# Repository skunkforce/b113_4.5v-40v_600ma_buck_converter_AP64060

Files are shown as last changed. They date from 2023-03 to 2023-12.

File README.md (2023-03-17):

# edgy_board number b113
This design is part of the [edgy board project](https://github.com/skunkforce/edgy_boards).  

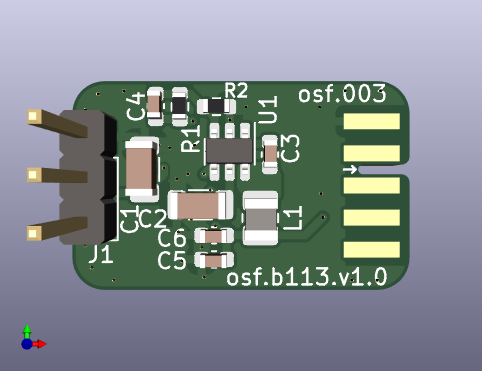
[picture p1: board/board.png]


# getting started
This repository uses submodules. After cloning use the command 

```$ git submodule update --init --recursive```

to pull the submodules before opening the project with kicad. 

# Tests
Tests can be found in [TESTS.md](TESTS.md)

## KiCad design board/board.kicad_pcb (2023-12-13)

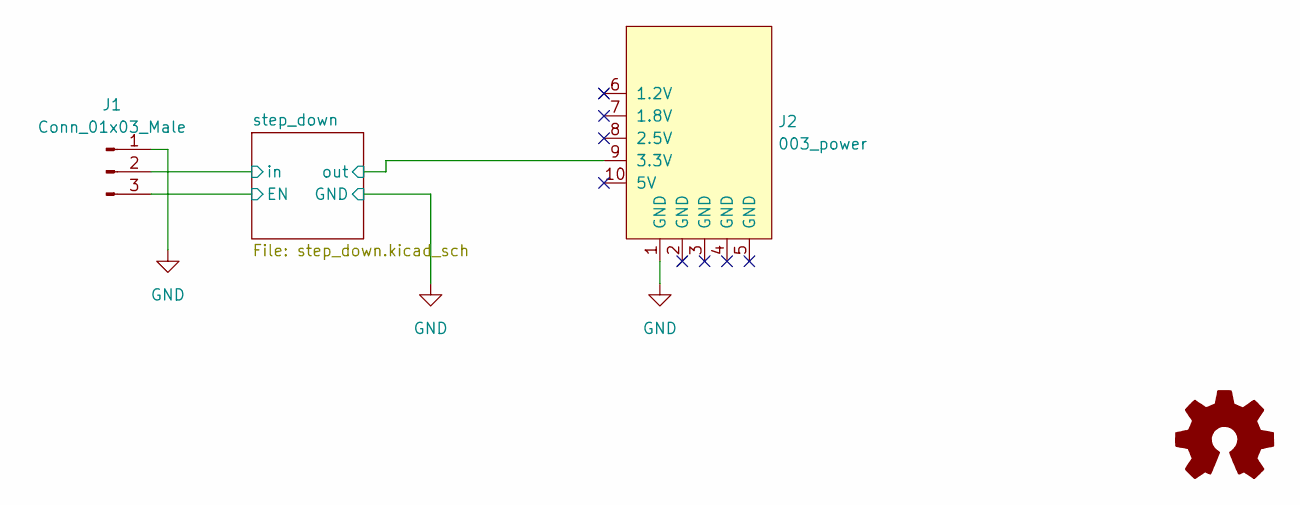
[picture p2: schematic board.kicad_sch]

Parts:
J1: Conn_01x03_Male; PinHeader_1x03_P2.54mm_Vertical
J2: 003_power; on_edge_2x05_host
LOGO1: Logo_Open_Hardware_Small; OSHW-Symbol_6.7x6mm_SilkScreen

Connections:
/step_down/EN: J1.3; also elsewhere on the board
/step_down/in: J1.2; also elsewhere on the board
/step_down/out: J2.9 (3.3V); also elsewhere on the board
GND: J1.1, J2.1 (GND); also elsewhere on the board

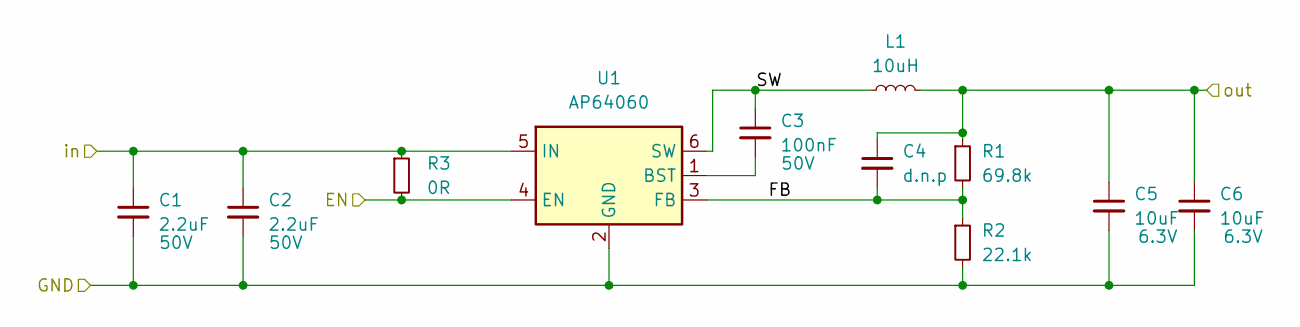
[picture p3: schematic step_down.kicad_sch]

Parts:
C1, C2: 2.2uF; C_1206_3216Metric; Voltage 50V
C3: 100nF; C_0603_1608Metric; Voltage 50V
C4: d.n.p; C_0603_1608Metric
C5, C6: 10uF; C_0603_1608Metric; Voltage 6.3V
L1: 10uH; L_1210_3225Metric; MPN CBC3225T100KR
R1: 69.8k; R_0603_1608Metric
R2: 22.1k; R_0603_1608Metric
R3: 0R; R_0402_1005Metric
U1: AP64060; TSOT-23-6

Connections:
/step_down/EN: R3.2, U1.4 (EN); also elsewhere on the board
/step_down/FB: C4.2, R1.2, R2.1, U1.3 (FB)
/step_down/SW: C3.1, L1.1, U1.6 (SW)
/step_down/in: C1.1, C2.1, R3.1, U1.5 (IN); also elsewhere on the board
/step_down/out: C4.1, C5.1, C6.1, L1.2, R1.1; also elsewhere on the board
GND: C1.2, C2.2, C5.2, C6.2, R2.2, U1.2 (GND); also elsewhere on the board
unnamed: C3.2, U1.1 (BST)

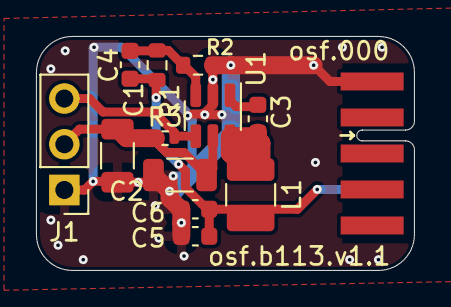
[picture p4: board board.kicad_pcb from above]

Board: 2 copper layers, 21.0 x 13.0 mm, 14 parts (1 on the bottom side), 7 nets.

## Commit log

2023-05-04 fixed incorrect part number
    [board.kicad_pcb, board.kicad_sch]
2023-12-13 used lower dc resistance inductor
    [board.kicad_pcb, board.kicad_sch, step_down.kicad_sch]
